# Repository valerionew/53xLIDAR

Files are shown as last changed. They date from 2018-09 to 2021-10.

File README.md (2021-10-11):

# 53xLIDAR

## Overview
Project for an opensource, all-in-one, solid state lidar.  
The lidar is made with 16 **VL53L1x** Time-of-flight IR ranging sensors.  

The sensors are operated by an **STM32F411RE** on two separate I2C buses, one for sensor 1-8, the other for 9-16. 
The XSHUTs are shared between two sensors on the two different I2C buses, while the sensors interrupts are separate for each sensor.   
For future use, there is an **LSM9DS1**, 9 DOF inertial sensor onboard.  

The lidar outputs the data via a virtual com port from the native Micro-USB, or via a 3.3V UART on a 4 pin JST-PH connector.  
Power (5V 100mA) is provided through the USB or via the 4 pin uart connector.

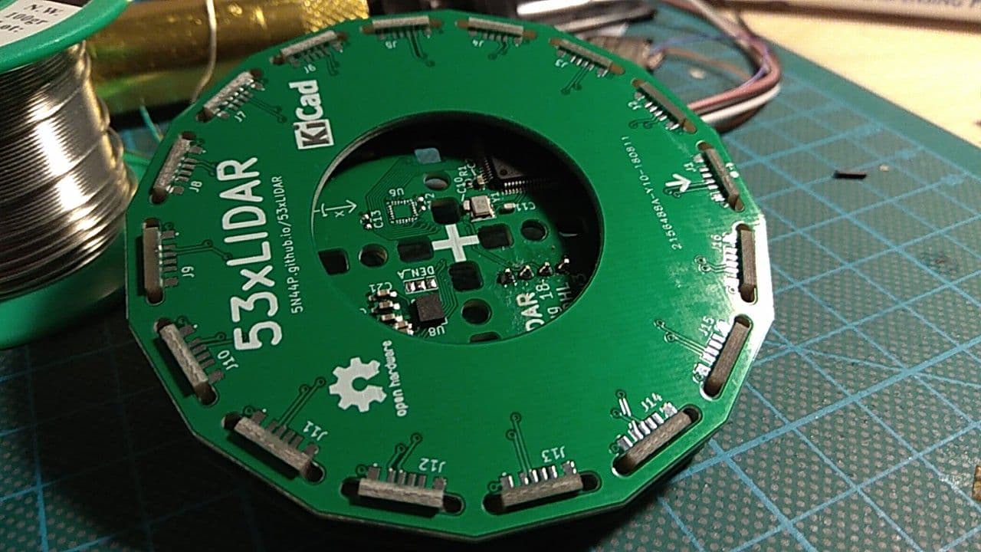
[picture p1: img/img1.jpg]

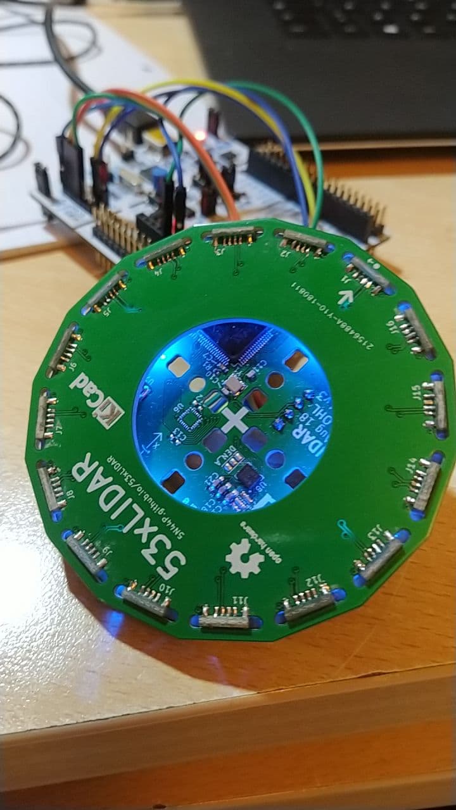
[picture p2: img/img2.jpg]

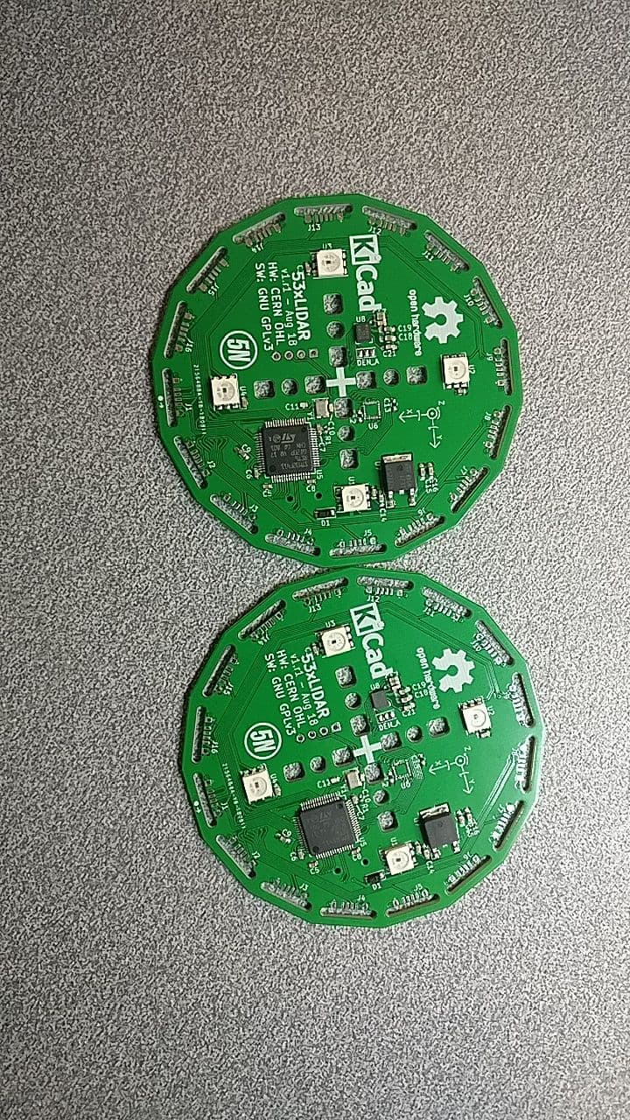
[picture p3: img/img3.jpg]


## Hardware
The hardware is designed in KiCAD and released under CERN OHL licence. 

It is formed by 16 sensor daughter boards, arranged in a 32 modules panel (only half panel is needed for one lidar, but for manufacturing reasons is made as a 32 modules panel); a bottom board containing all the electronics; a top board which brings the I2C line to the sensors and adds mechanical strenght and protection to the sensors.

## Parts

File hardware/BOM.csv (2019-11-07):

Id | Ref | Package | Quantity | Value
1 | C21 | C_0603_HandSoldering | 1 | 10n 16V
3 | J17 | USB_Mini-B_AdamTech_MUSB-B5-S-VT-TSMT-1_SMD_Vertical | 1 | USB_OTG
5 | U5 | LQFP-64_10x10mm_Pitch0.5mm | 1 | STM32F411RETx
7 | D1 | D_SOD-123 | 1 | USL1M
8 | J18 | JST_PH_B4B-PH-SM4-TB_04x2.00mm_Straight | 1 | UART_EXT
9 | J23 | JST_PH_B6B-PH-SM4-TB_06x2.00mm_Straight | 1 | SPI1_EXT
10 | U1;U2;U3;U4 | LED_WS2812-PLCC6 | 4 | WS2812S
11 | U7 | TO-252-2 | 1 | KF33_DPAK
13 | U6 | QFN-24_3x3mm_Pitch0.4mm | 1 | MPU-9250
14 | C10;C11 | C_0402 | 2 | 15p
15 | Y1 | Crystal_SMD_3225-4pin_3.2x2.5mm | 1 | 24MHz SR PASSIVES 3225-24M-SR
23 | R1 | R_0402 | 1 | 10k
24 | U8 | LGA-24L_3x3.5mm_Pitch0.43mm | 1 | LSM9DS1
25 | C9;C14;C15;C16;C18;C19;C2_MODULESx16 | C_0603_HandSoldering | 22 | 4.7u
26 | C1;C2;C3;C4;C5;C6;C7;C8;C12;C13;C17;C20;C22;C1_MODULESx16 | C_0603 | 29 | 100n
28 | R5_MODULESx16;R6_MODULESx16;R7_MODULESx16;R8_MODULESx16 | R_0603 | 64 | 10k
30 | U1_MODULES | ST_VL53L_HandSoldering | 16 | VL53L1X

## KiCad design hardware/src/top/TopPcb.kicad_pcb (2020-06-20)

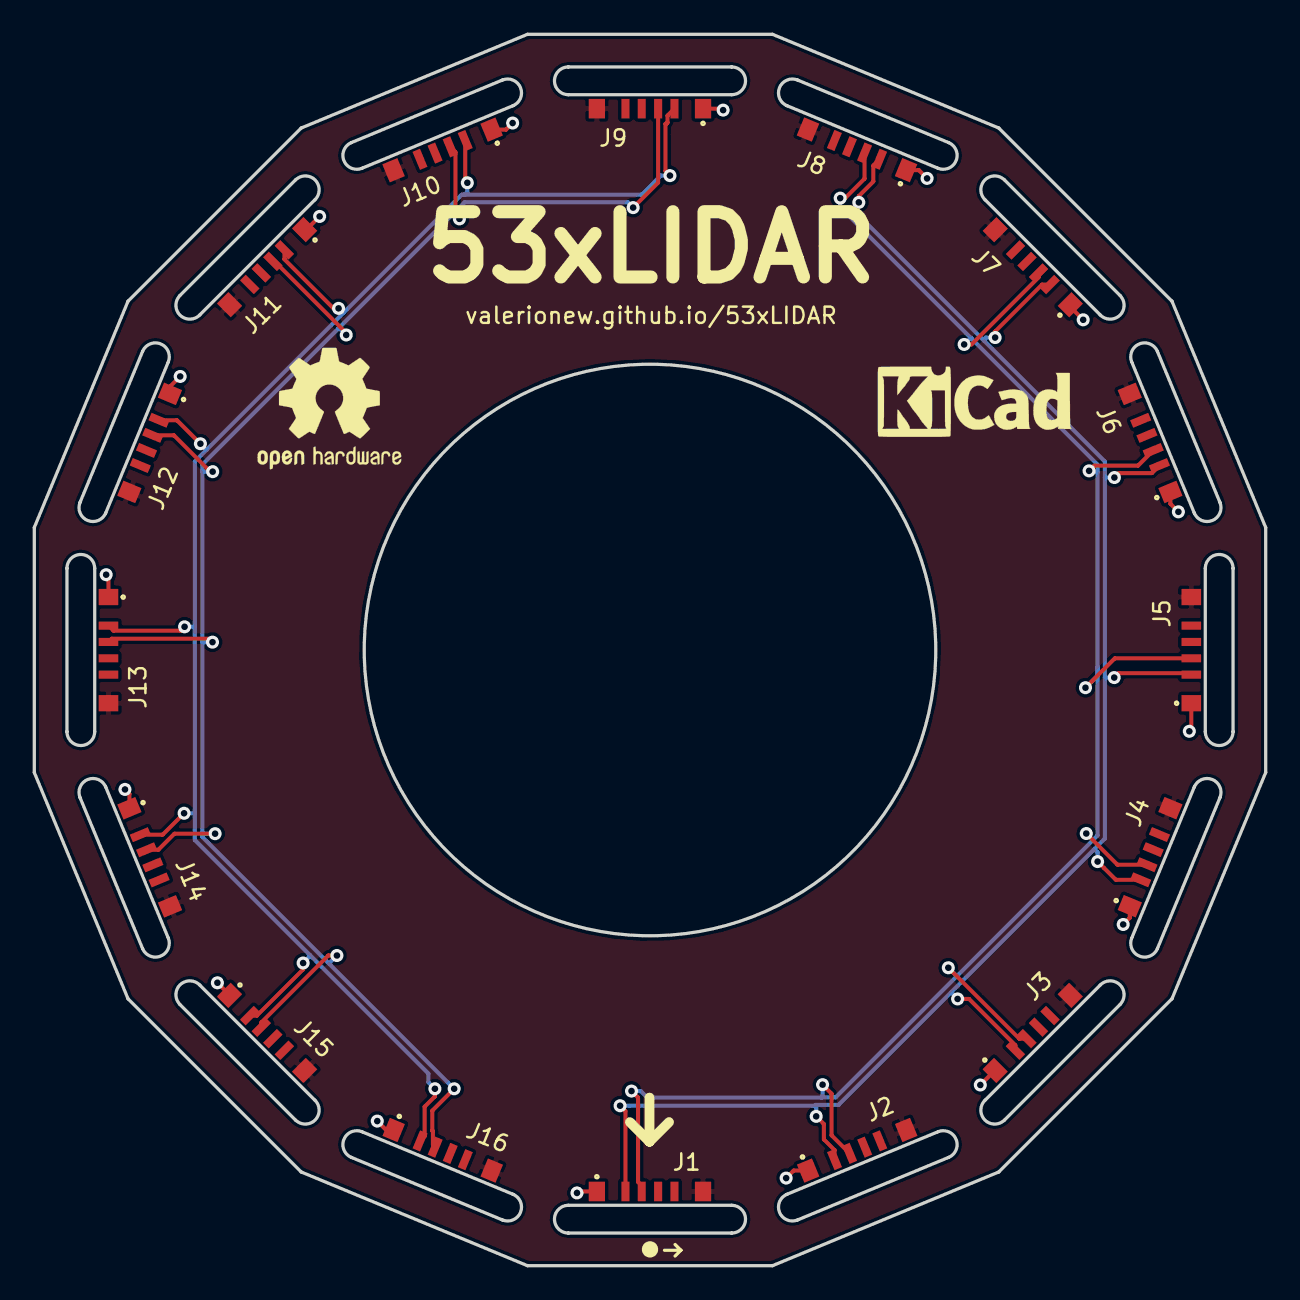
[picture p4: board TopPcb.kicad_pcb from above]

Board: 2 copper layers, 75.4 x 75.4 mm, 16 parts (0 on the bottom side), 6 nets.

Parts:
J1, J2, J3, J4, J5, J6, J7, J8, J9, J10, J11, J12, J13, J14, J15, J16: CONN_01X06; CONN

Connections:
+3V3: J1.1, J2.1, J3.1, J4.1, J5.1, J6.1, J7.1, J8.1, J9.1, J10.1, J11.1, J12.1, J13.1, J14.1, J15.1, J16.1
GND: J1.6, J2.6, J3.6, J4.6, J5.6, J6.6, J7.6, J8.6, J9.6, J10.6, J11.6, J12.6, J13.6, J14.6, J15.6, J16.6
SCL1: J1.3, J2.3, J3.3, J4.3, J5.3, J6.3, J7.3, J8.3
SCL2: J9.3, J10.3, J11.3, J12.3, J13.3, J14.3, J15.3, J16.3
SDA1: J1.2, J2.2, J3.2, J4.2, J5.2, J6.2, J7.2, J8.2
SDA2: J9.2, J10.2, J11.2, J12.2, J13.2, J14.2, J15.2, J16.2

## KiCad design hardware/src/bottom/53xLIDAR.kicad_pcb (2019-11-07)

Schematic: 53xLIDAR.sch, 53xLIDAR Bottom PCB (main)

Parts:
BOOT0_TP1: BOOT0; Measurement_Point_Round-SMD-Pad_Small
C1, C2, C3, C4, C5, C6, C7, C8, C12, C13, C17, C20, C22: 100n; C_0603
C9, C14, C15, C16, C18, C19: 4.7u; C_0603_HandSoldering
C10, C11: 15p; C_0402
C21: 10n 16V; C_0603_HandSoldering
D1: USL1M; D_SOD-123
J1, J2, J3, J4, J5, J6, J7, J8, J9, J10, J11, J12, J13, J14, J15, J16: CONN_01X06; CONN
J17: USB_OTG; miniusb_MUSB-B5-S-VT-TSMT-1
J18: UART_EXT; JST_PH_B4B-PH-SM4-TB_04x2.00mm_Straight
J19: I2C1_DEBUG; Pad_test_SMD_1x03_Pitch1.27mm
J20: I2C2_DEBUG; Pad_test_SMD_1x03_Pitch1.27mm
J21: UART_DEBUG; Pad_test_SMD_1x03_Pitch1.27mm
J22: SWD; Pin_Header_Straight_1x04_Pitch2.54mm
J23: SPI1_EXT; JST_PH_B6B-PH-SM4-TB_06x2.00mm_Straight
J25: GS3
R1: 10k; R_0402
U1, U2, U3, U4: WS2812S; LED_WS2812-PLCC6
U5: STM32F411RETx; LQFP-64_10x10mm_Pitch0.5mm
U6: MPU-9250; QFN-24_3x3mm_Pitch0.4mm
U7: KF33_DPAK; TO-252-2
U8: LSM9DS1; LGA-24L_3x3.5mm_Pitch0.43mm
Y1: 24MHz SR PASSIVES 3225-24M-SR; Crystal_SMD_3225-4pin_3.2x2.5mm

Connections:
+3V3: C5.1, C6.1, C7.1, C8.1, C12.2, C15.1, C16.1, C17.1, C18.1, C19.1, C20.2, J1.1, J2.1, J3.1, J4.1, J5.1, J6.1, J7.1, J8.1, J9.1, J10.1, J11.1, J12.1, J13.1, J14.1, J15.1, J16.1, J22.1, J23.1, J25.1, U5.13 (VREF+), U5.19 (VDD), U5.32 (VDD), U5.48 (VDD), U5.64 (VDD), U6.1, U6.8, U6.13, U7.3 (VO), U8.1, U8.3, U8.22, U8.23
EXT_CS: J23.5, U5.53 (PC12/I2S3_SD/SDIO_CK/SPI3_MOSI)
IMU_CS: U5.61 (I2C1_SCL/I2C3_SDA/I2S5_SD/SDIO_D4/SPI5_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), U6.22, U8.7
IMU_CS_MAG: U5.52 (PC11/ADC1_EXTI11/I2S3_ext_SD/SDIO_D3/SP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), U8.8
IMU_DRDY_MAG: U5.34 (I2S2_CK/I2S4_CK/SPI2_SCK/SPI4_SCK/TIM1_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), U8.9
IMU_INT: U5.54 (PD2/SDIO_CMD/TIM3_ETR), U6.12, U8.11
IMU_INT_MAG: U5.51 (PC10/I2S3_CK/SDIO_D2/SPI3_SCK), U8.10
INT1: J1.5, U5.24 (PC4/ADC1_IN14)
INT2: J2.5, U5.25 (PC5/ADC1_IN15)
INT3: J3.5, U5.26 (ADC1_IN8/I2S5_CK/SPI5_SCK/TIM1_CH2N/TIM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)
INT4: J4.5, U5.27 (ADC1_IN9/I2S5_WS/SPI5_NSS/TIM1_CH3N/TIM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)
INT5: J5.5, U5.28 (BOOT1/PB2)
INT6: J6.5, U5.35 (I2S2_ext_SD/SDIO_D6/SPI2_MISO/TIM1_CH2N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)
INT7: J7.5, U5.36 (ADC1_EXTI15/I2S2_SD/RTC_REFIN/SDIO_CK/S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)
INT8: J8.5, U5.37 (PC6/I2S2_MCK/SDIO_D6/TIM3_CH1/USART6_TX)
INT9: J9.5, U5.38 (PC7/I2S2_CK/I2S3_MCK/SDIO_D7/SPI2_SCK/T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)
INT10: J10.5, U5.39 (PC8/SDIO_D0/TIM3_CH3/USART6_CK)
INT11: J11.5, U5.4 (PC15/ADC1_EXTI15/RCC_OSC32_OUT)
INT12: J12.5, U5.2 (PC13/ANTI_TAMP/RTC_AF1)
INT13: J13.5, U5.3 (PC14/RCC_OSC32_IN)
INT14: J14.5, U5.62 (I2C1_SDA/I2C2_SDA/I2S2_WS/SDIO_D5/SPI2_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)
INT15: J15.5, U5.14 (ADC1_IN0/SYS_WKUP/TIM2_CH1/TIM2_ETR/TIM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)
INT16: J16.5, U5.15 (ADC1_IN1/I2S4_SD/SPI4_MOSI/TIM2_CH2/TIM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)
unnamed: BOOT0_TP1.1, R1.1, U5.60 (BOOT0)
unnamed: C9.2, U5.30 (VCAP1)
unnamed: C10.1, U5.5 (PH0/RCC_OSC_IN), Y1.3
unnamed: C11.1, U5.6 (PH1/RCC_OSC_OUT), Y1.1
unnamed: C13.2, U6.10
unnamed: C21.2, U8.21
unnamed: C22.1, U8.24
unnamed: D1.1, U1.3
unnamed: J25.2, U8.13
unnamed: U1.1, U2.2
unnamed: U2.1, U3.2
unnamed: U3.1, U4.2
SCL1: J1.3, J2.3, J3.3, J4.3, J5.3, J6.3, J7.3, J8.3, J19.1, U5.58 (I2C1_SCL/TIM4_CH1/USART1_TX/PB6)
SCL2: J9.3, J10.3, J11.3, J12.3, J13.3, J14.3, J15.3, J16.3, J20.1, U5.29 (I2C2_SCL/I2S2_CK/I2S3_MCK/SDIO_D7/SPI2_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)
SCL_IMU: J23.4, U5.33 (I2C2_SMBA/I2S2_WS/I2S3_CK/I2S4_WS/SPI2_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), U5.41 (I2C3_SCL/RCC_MCO_1/SDIO_D1/TIM1_CH1/USA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), U6.23, U8.2
SDA1: J1.2, J2.2, J3.2, J4.2, J5.2, J6.2, J7.2, J8.2, J19.2, U5.59 (I2C1_SDA/SDIO_D0/TIM4_CH2/USART1_RX/PB7)
SDA2: J9.2, J10.2, J11.2, J12.2, J13.2, J14.2, J15.2, J16.2, J20.2, U5.55 (I2C2_SDA/I2S1_CK/I2S3_CK/SPI1_SCK/SPI3_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)
SDA_IMU: J23.2, U5.40 (PC9/I2C3_SDA/I2S_CKIN/RCC_MCO_2/SDIO_D1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), U5.57 (I2C1_SMBA/I2S1_SD/I2S3_SD/SDIO_D3/SPI1_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), U6.24, U8.4
SPI1_MISO: J23.3, U5.56 (I2C3_SDA/I2S3_ext_SD/SDIO_D0/SPI1_MISO/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), U6.9, U8.5, U8.6
SWCLK_PROGRAMMING: J22.3, U5.49 (SYS_JTCK-SWCLK/PA14)
SWDIO_PROGRAMMING: J22.2, U5.46 (SYS_JTMS-SWDIO/PA13)
USART_DEBUG_RX: J21.1, U5.17 (ADC1_IN3/I2S2_MCK/TIM2_CH4/TIM5_CH4/TIM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)
USART_DEBUG_TX: J21.2, U5.16 (ADC1_IN2/I2S_CKIN/TIM2_CH3/TIM5_CH3/TIM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)
USART_EXT_RX: J18.2, U5.43 (I2S5_SD/SPI5_MOSI/TIM1_CH3/USART1_RX/US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)
USART_EXT_TX: J18.1, U5.42 (I2C3_SMBA/SDIO_D2/TIM1_CH2/USART1_TX/US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)
USB_D+: J17.3, U5.45 (SPI5_MISO/TIM1_ETR/USART1_RTS/USART6_RX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)
USB_D-: J17.2, U5.44 (ADC1_EXTI11/SPI4_MISO/TIM1_CH4/USART1_C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)
USB_VBUS: C1.1, C2.1, C3.1, C4.1, C14.1, D1.2, J17.1, J18.3, U1.5, U2.3, U2.5, U3.3, U3.5, U4.3, U4.5, U7.1 (VI)
WS2812S_DATA: U1.2, U5.50 (ADC1_EXTI15/I2S1_WS/I2S3_WS/SPI1_NSS/SP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)
XSHUT1: J8.4, J9.4, U5.8 (PC0/ADC1_IN10)
XSHUT2: J7.4, J10.4, U5.9 (PC1/ADC1_IN11)
XSHUT3: J6.4, J11.4, U5.10 (PC2/ADC1_IN12/I2S2_ext_SD/SPI2_MISO)
XSHUT4: J5.4, J12.4, U5.11 (PC3/ADC1_IN13/I2S2_SD/SPI2_MOSI)
XSHUT5: J4.4, J13.4, U5.20 (ADC1_IN4/I2S1_WS/I2S3_WS/SPI1_NSS/SPI3_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)
XSHUT6: J3.4, J14.4, U5.21 (ADC1_IN5/I2S1_CK/SPI1_SCK/TIM2_CH1/TIM2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)
XSHUT7: J2.4, J15.4, U5.22 (ADC1_IN6/I2S2_MCK/SDIO_CMD/SPI1_MISO/TI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)
XSHUT8: J1.4, J16.4, U5.23 (ADC1_IN7/I2S1_SD/SPI1_MOSI/TIM1_CH1N/TI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)

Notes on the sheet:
SET THE UNUSED ONE TO HIGH IMPEDANCE

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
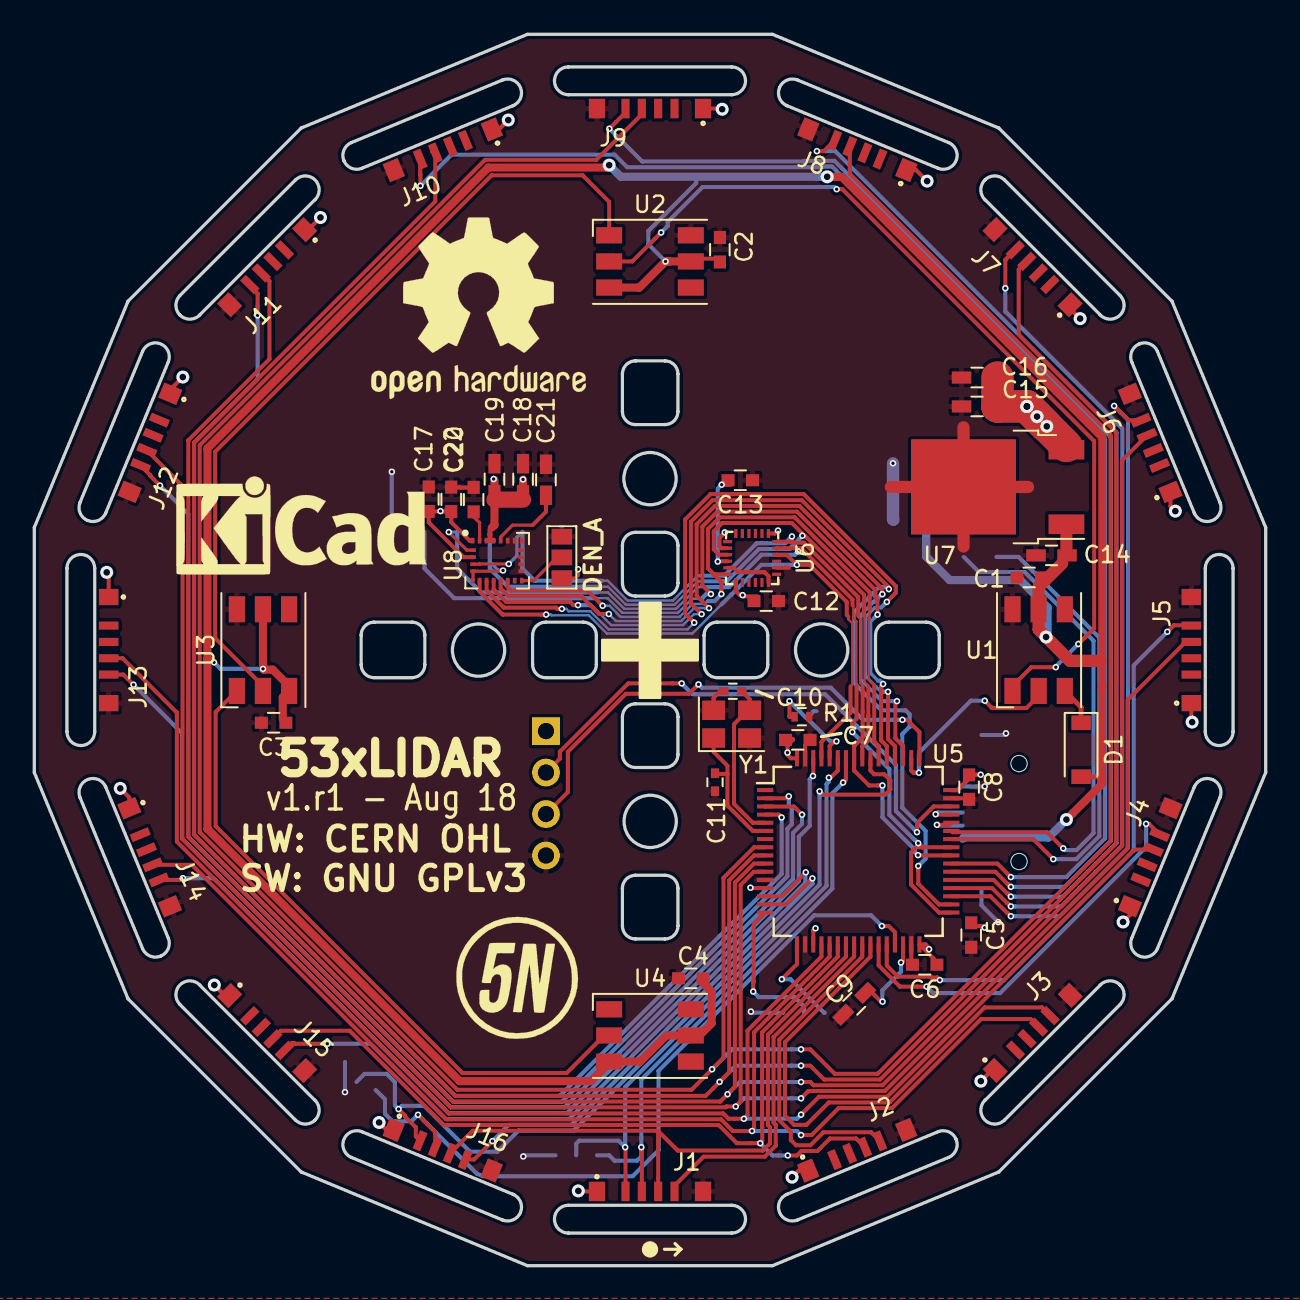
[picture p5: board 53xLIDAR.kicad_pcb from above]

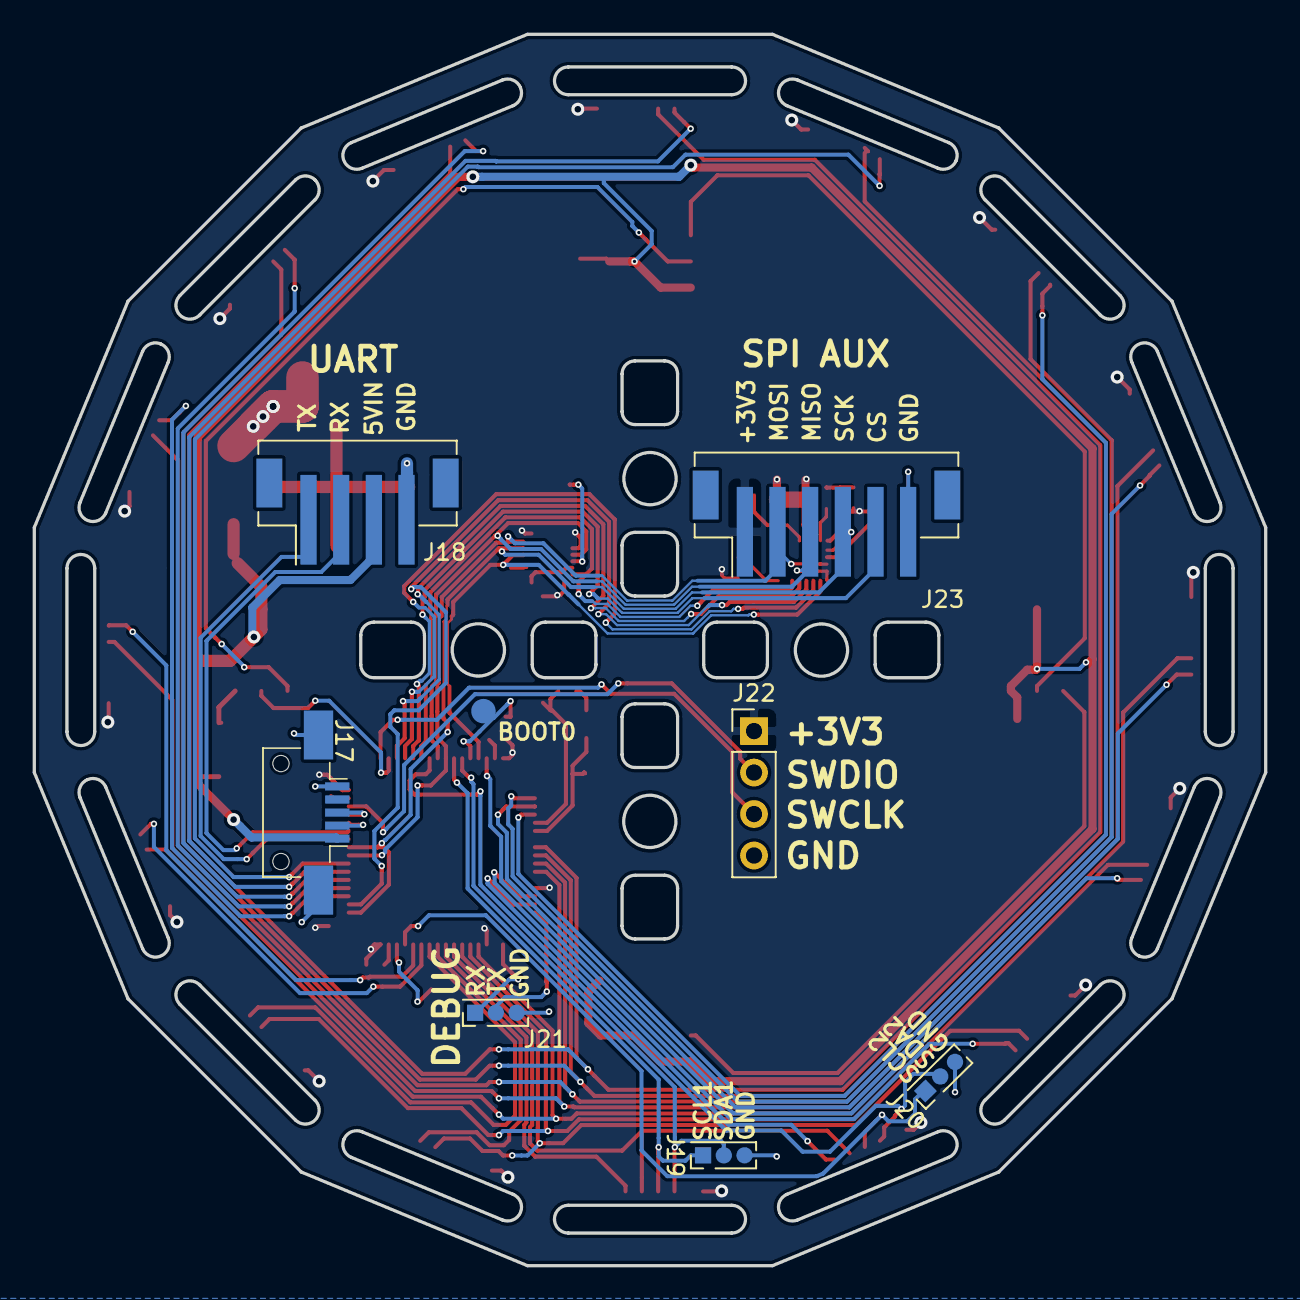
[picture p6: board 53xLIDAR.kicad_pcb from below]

Board: 2 copper layers, 75.4 x 75.4 mm, 58 parts (8 on the bottom side), 61 nets.

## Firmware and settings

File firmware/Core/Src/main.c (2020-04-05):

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

/* Includes ------------------------------------------------------------------*/
#include "main.h"
#include "usb_device.h"

/* USER CODE BEGIN Includes */
#include "VL53L1X_api.h"

#include "WS2812.h"
/* USER CODE END Includes */

I2C_HandleTypeDef hi2c1;
I2C_HandleTypeDef hi2c2;
I2C_HandleTypeDef hi2c3;

SPI_HandleTypeDef hspi3;

UART_HandleTypeDef huart1;
UART_HandleTypeDef huart2;

void SystemClock_Config(void);
static void MX_GPIO_Init(void);
static void MX_I2C1_Init(void);
static void MX_I2C2_Init(void);
static void MX_I2C3_Init(void);
static void MX_SPI3_Init(void);
static void MX_USART1_UART_Init(void);
static void MX_USART2_UART_Init(void);
/* USER CODE BEGIN 0 */
struct Gpio {
	GPIO_TypeDef * const port;
	const uint16_t mask;
};

struct Gpio leds = { GPIOA, GPIO_PIN_15 };

struct Gpio xshut[] = { { GPIOC, GPIO_PIN_0 }, { GPIOC, GPIO_PIN_1 }, { GPIOC,
GPIO_PIN_2 }, { GPIOC, GPIO_PIN_3 }, { GPIOA, GPIO_PIN_4 }, { GPIOA,
GPIO_PIN_5 }, { GPIOA, GPIO_PIN_6 }, { GPIOA, GPIO_PIN_7 }, };
/*
 uint8_t interruptLidar[] = {
 PC4, PC5, PB0, PB1, PB2, PB14, PB15, PC6, PC7, PC8, PC15, PC13, PC14, PB9, PA0, PA1
 };
 */

struct {
	uint16_t dev;
	uint8_t valid;
} sensors[16];

int enableSensor(int i) {

	uint16_t dev = 0x29 << 1;
	if (i >= 8) {
		dev |= 0x100; //if 9th bit is 0 it will use I2C1,if 1 will use i2c2
	}
	
	VL53L1X_Error err;
	uint8_t is_booted = 0;
	do{
		err = VL53L1X_BootState(dev, &is_booted);
		HAL_Delay(2);
	}while(!is_booted && err == VL53L1_ERROR_NONE);
	
	if (err != VL53L1_ERROR_NONE) {
		uint8_t msg[] = "VL53L1X_BootState failed    \n";
		uint8_t len = sizeof(msg) - 1;
		msg[len - 1 - 1] = i + '0';
		msg[len - 3 - 1] = err + '0';
		HAL_UART_Transmit(&huart1, msg, len, 0xFFFF);
		return 1;
	} else {
		uint8_t msg[] = "VL53L1X_BootState OK  \n";
		uint8_t len = sizeof(msg) - 1;
		msg[len - 1 - 1] = i + '0';
		HAL_UART_Transmit(&huart1, msg, len, 0xFFFF);
	}
	
	/* Sensor Initialization */
	err = VL53L1X_SensorInit(dev);
	if (err != VL53L1_ERROR_NONE) {
		uint8_t msg[] = "VL53L1X_SensorInit failed    \n";
		uint8_t len = sizeof(msg) - 1;
		msg[len - 1 - 1] = i + '0';
		msg[len - 3 - 1] = err + '0';
		HAL_UART_Transmit(&huart1, msg, len, 0xFFFF);
		return 3;
	} else {
		uint8_t msg[] = "VL53L1X_SensorInit OK  \n";
		uint8_t len = sizeof(msg) - 1;
		msg[len - 1 - 1] = i + '0';
		HAL_UART_Transmit(&huart1, msg, len, 0xFFFF);
	}
	
	/* Modify the default configuration */
	err = VL53L1X_SetI2CAddress(dev, (0x29 + i + 1) << 1);
	dev = (0x29 + i + 1) << 1;
	if (i >= 8) {
		dev |= 0x100; //if 9th bit is 0 it will use I2C1,if 1 will use i2c2
	}
	if (err != VL53L1_ERROR_NONE) {
		uint8_t msg[] = "VL53L1X_SetI2CAddress failed    \n";
		uint8_t len = sizeof(msg) - 1;
		msg[len - 1 - 1] = i + '0';
		msg[len - 3 - 1] = err + '0';
		HAL_UART_Transmit(&huart1, msg, len, 0xFFFF);
		return 2;
	} else {
		uint8_t msg[] = "VL53L1X_SetI2CAddress OK  \n";
		uint8_t len = sizeof(msg) - 1;
		msg[len - 1 - 1] = i + '0';
		HAL_UART_Transmit(&huart1, msg, len, 0xFFFF);
	}
	
	err = VL53L1X_SetDistanceMode(dev, 2); // 2 = VL53L1X_DISTANCEMODE_LONG
	if (err != VL53L1_ERROR_NONE) {
		uint8_t msg[] = "VL53L1X_SetDistanceMode failed    \n";
		uint8_t len = sizeof(msg) - 1;
		msg[len - 1 - 1] = i + '0';
		msg[len - 3 - 1] = err + '0';
		HAL_UART_Transmit(&huart1, msg, len, 0xFFFF);
		return 5;
	} else {
		uint8_t msg[] = "VL53L1X_SetDistanceMode OK  \n";
		uint8_t len = sizeof(msg) - 1;
		msg[len - 1 - 1] = i + '0';
		HAL_UART_Transmit(&huart1, msg, len, 0xFFFF);
	}

	err = VL53L1X_SetTimingBudgetInMs(dev, 20);
	if (err != VL53L1_ERROR_NONE) {
		uint8_t msg[] =
				"VL53L1X_SetTimingBudgetInMs failed    \n";
		uint8_t len = sizeof(msg) - 1;
		msg[len - 1 - 1] = i + '0';
		msg[len - 3 - 1] = err + '0';
		HAL_UART_Transmit(&huart1, msg, len, 0xFFFF);
		return 6;
	} else {
		uint8_t msg[] = "VL53L1X_SetTimingBudgetInMs OK  \n";
		uint8_t len = sizeof(msg) - 1;
		msg[len - 1 - 1] = i + '0';
		HAL_UART_Transmit(&huart1, msg, len, 0xFFFF);
	}

	err = VL53L1X_SetInterMeasurementInMs(dev, 25);
	if (err != VL53L1_ERROR_NONE) {
		uint8_t msg[] =
				"VL53L1X_SetInterMeasurementInMs failed    \n";
		uint8_t len = sizeof(msg) - 1;
		msg[len - 1 - 1] = i + '0';
		msg[len - 3 - 1] = err + '0';
		HAL_UART_Transmit(&huart1, msg, len, 0xFFFF);
		return 7;
	} else {
		uint8_t msg[] = "VL53L1X_SetInterMeasurementInMs OK  \n";
		uint8_t len = sizeof(msg) - 1;
		msg[len - 1 - 1] = i + '0';
		HAL_UART_Transmit(&huart1, msg, len, 0xFFFF);
	}

	err = VL53L1X_StartRanging(dev);
	if (err != VL53L1_ERROR_NONE) {
		uint8_t msg[] = "VL53L1X_StartRanging failed    \n";
		uint8_t len = sizeof(msg) - 1;
		msg[len - 1 - 1] = i + '0';
		msg[len - 3 - 1] = err + '0';
		HAL_UART_Transmit(&huart1, msg, len, 0xFFFF);
		return 8;
	} else {
		uint8_t msg[] = "VL53L1X_StartRanging OK  \n";
		uint8_t len = sizeof(msg) - 1;
		msg[len - 1 - 1] = i + '0';
		HAL_UART_Transmit(&huart1, msg, len, 0xFFFF);
	}
	
	sensors[i].dev = dev;
	sensors[i].valid = 1;
	
	return 0;
}

void scan(I2C_HandleTypeDef *hi2c) {
	for (int i = 1; i < 128; i++) {
		/*
		 * the HAL wants a left aligned i2c address
		 * &hi2c1 is the handle
		 * (uint16_t)(i<<1) is the i2c address left aligned
		 * retries 2
		 * timeout 2
		 */
		HAL_StatusTypeDef result = HAL_I2C_IsDeviceReady(hi2c, (i << 1), 2, 2);
		if (result != HAL_OK) // HAL_ERROR or HAL_BUSY or HAL_TIMEOUT
				{
			HAL_UART_Transmit(&huart1, (uint8_t*)".", 1, 0xFFFF);
		}
		if (result == HAL_OK) {
			char buff[80];
			sprintf(buff, "0x%X\n", i << 1);
			HAL_UART_Transmit(&huart1, (uint8_t*)buff, strlen(buff), 0xFFFF);
		}
	}
	char buff[] = "\nSCAN FINISH\n";
	HAL_UART_Transmit(&huart1, (uint8_t*)buff, strlen(buff), 0xFFFF);
}

uint32_t ledColor[4];

void updateLed() {
	static int lastGreen = 0;
	static uint8_t first = 1;
	static uint32_t last = 0;
	if (!first) {
		// set back previus led
		if (lastGreen == 0) {
			ledColor[3] = last;
		} else {
			ledColor[lastGreen - 1] = last;
		}
	} else {
		first = 0;
	}
	//set current to blue and increment
	last = ledColor[lastGreen];
	ledColor[lastGreen] = 0x00FF00; //blue
	lastGreen++;

	//avoid overflow
	if (lastGreen >= 4) {
		lastGreen = 0;
	}

	sendColors(ledColor, 4);
}

/* USER CODE END 0 */

/**
  * @brief  The application entry point.
  * @retval int
  */
int main(void)
{
  /* MCU Configuration--------------------------------------------------------*/

  /* Reset of all peripherals, Initializes the Flash interface and the Systick. */
  HAL_Init();

  /* Configure the system clock */
  SystemClock_Config();

  /* Initialize all configured peripherals */
  MX_GPIO_Init();
  MX_I2C1_Init();
  MX_I2C2_Init();
  MX_I2C3_Init();
  MX_SPI3_Init();
  MX_USART1_UART_Init();
  MX_USART2_UART_Init();
  MX_USB_DEVICE_Init();
  /* USER CODE BEGIN 2 */
	// be sure to put all xshut to low
	HAL_GPIO_WritePin(GPIOC, GPIO_PIN_0 | GPIO_PIN_1 | GPIO_PIN_2 | GPIO_PIN_3,
			GPIO_PIN_RESET);
	HAL_GPIO_WritePin(GPIOA, GPIO_PIN_4 | GPIO_PIN_5 | GPIO_PIN_6 | GPIO_PIN_7,
			GPIO_PIN_RESET);

	for (int i = 0; i < 4; i++) {
		ledColor[i] = 0x0000FF; //set to blue
	}
	sendColors(ledColor, 4);

	HAL_Delay(1000);

	for (int i = 0; i < 8; i++) {
		HAL_GPIO_WritePin(xshut[i].port, xshut[i].mask, GPIO_PIN_SET);
		HAL_Delay(10);
		int error = 0;
		error += enableSensor(i); //i2c1
		error += enableSensor(i + 8); //i2c2

		if (error) {
			//HAL_GPIO_WritePin(xshut[i].port, xshut[i].mask, GPIO_PIN_RESET);
			ledColor[i / 2] = 0xFF0000; //set to red
			sendColors(ledColor, 4);
		} else {
			if (ledColor[i / 2] != 0xFF0000) {
				ledColor[i / 2] = 0; //turn off led
				sendColors(ledColor, 4);
			}
		}
	}
	scan(&hi2c1);
	scan(&hi2c2);

	int fps = 0;
	uint8_t buff[80];

	uint8_t msg[5]; // ~, 3 byte payload, checksum
	uint32_t start = HAL_GetTick();
	while (1) {
	
		for (int i = 0; i < 16; i++) {
		
			if (sensors[i].valid) {
				uint8_t ready = 0;
				VL53L1X_ERROR err = VL53L1X_CheckForDataReady(sensors[i].dev, &ready);
				
				if (!err && ready) {
					uint8_t range_status;
					err = VL53L1X_GetRangeStatus(sensors[i].dev, &range_status);
					if (err) {
						sprintf((char*) buff, "VL53L1X_GetRangeStatus error %d on sensor %d\n", err, i);
						HAL_UART_Transmit(&huart1, buff, strlen((char*) buff), 0xFFFF);
						continue;
					}
					
					uint16_t distance_mm;
					err = VL53L1X_GetDistance(sensors[i].dev, &distance_mm);
					if (err) {
						sprintf((char*) buff, "VL53L1X_GetDistance error %d on sensor %d\n", err, i);
						HAL_UART_Transmit(&huart1, buff, strlen((char*) buff), 0xFFFF);
						continue;
					}
					
					err = VL53L1X_ClearInterrupt(sensors[i].dev);
					if (err) {
						sprintf((char*) buff, "VL53L1X_ClearInterrupt error %d on sensor %d\n", err, i);
						HAL_UART_Transmit(&huart1, buff, strlen((char*) buff), 0xFFFF);
						continue;
					}

					msg[0] = '~';
					msg[1] = i;
					msg[2] = distance_mm;
					msg[3] = distance_mm >> 8;
					msg[4] = msg[0] + msg[1] + msg[2] + msg[3];

					sprintf((char*) buff, "%x\t%d\n", i, distance_mm);
					HAL_UART_Transmit(&huart1, buff, strlen((char*) buff), 0xFFFF);

					fps++;
				} else if (err) {
					sprintf((char*) buff, "VL53L1X_CheckForDataReady error %d on sensor %d\n", err, i);
					HAL_UART_Transmit(&huart1, buff, strlen((char*) buff), 0xFFFF);
					/*
					 maxErr--;
					 if (!maxErr){
					 sprintf((char*) buff, "reset\n");
					 HAL_UART_Transmit(&huart1, buff, strlen((char*) buff), 0xFFFF);
					 scan(&hi2c1);
					 MX_I2C1_Init();
					 scan(&hi2c1);
					 }
					 */
				} else {
					//sprintf((char*) buff, "not ready\n");0
					//HAL_UART_Transmit(&huart1, buff, strlen((char*) buff), 0xFFFF);
				}
			}
		}

		static uint32_t startLedSpin = 0;
		if (HAL_GetTick() - startLedSpin >= 100) {
			startLedSpin = HAL_GetTick();
			updateLed();
		}

		if (HAL_GetTick() - start >= 1000) {
			start = HAL_GetTick();
			sprintf((char*) buff, "FPS: %d\n", fps);
			HAL_UART_Transmit(&huart1, buff, strlen((char*) buff), 0xFFFF);
			fps = 0;
		}

	}
  /* USER CODE END 2 */

  /* Infinite loop */
  /* USER CODE BEGIN WHILE */
  while (1)
  {
    /* USER CODE END WHILE */

    /* USER CODE BEGIN 3 */
  }
  /* USER CODE END 3 */
}

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


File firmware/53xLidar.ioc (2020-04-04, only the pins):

Mcu.UserName=STM32F411RETx
PA0-WKUP.Signal=GPIO_Input
PA1.Signal=GPIO_Input
PA10.Signal=USART1_RX
PA11.Signal=USB_OTG_FS_DM
PA12.Signal=USB_OTG_FS_DP
PA13.Signal=SYS_JTMS-SWDIO
PA14.Signal=SYS_JTCK-SWCLK
PA15.Signal=GPIO_Output
PA2.Signal=USART2_TX
PA3.Signal=USART2_RX
PA4.Signal=GPIO_Output
PA5.Signal=GPIO_Output
PA6.Signal=GPIO_Output
PA7.Signal=GPIO_Output
PA8.Signal=I2C3_SCL
PA9.Signal=USART1_TX
PB0.Signal=GPIO_Input
PB1.Signal=GPIO_Input
PB10.Signal=I2C2_SCL
PB12.Signal=SPI3_SCK
PB14.Signal=GPIO_Input
PB15.Signal=GPIO_Input
PB2.Signal=GPIO_Input
PB3.Signal=I2C2_SDA
PB4.Signal=SPI3_MISO
PB5.Signal=SPI3_MOSI
PB6.Signal=I2C1_SCL
PB7.Signal=I2C1_SDA
PB8.Signal=GPIO_Output
PB9.Signal=GPIO_Input
PC0.Signal=GPIO_Output
PC1.Signal=GPIO_Output
PC12.Signal=GPIO_Output
PC13-ANTI_TAMP.Signal=GPIO_Input
PC14-OSC32_IN.Signal=GPIO_Input
PC15-OSC32_OUT.Signal=GPIO_Input
PC2.Signal=GPIO_Output
PC3.Signal=GPIO_Output
PC4.Signal=GPIO_Input
PC5.Signal=GPIO_Input
PC6.Signal=GPIO_Input
PC7.Signal=GPIO_Input
PC8.Signal=GPIO_Input
PC9.Signal=I2C3_SDA
PD2.Signal=GPIO_Input

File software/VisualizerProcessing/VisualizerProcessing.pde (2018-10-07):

import processing.serial.*;

int bgcolor = 0xff;     // Background color
int fgcolor = 0;  // Fill color
Serial myPort;       // The serial port

float points[] = new float[16];
int pointsColor[] = new color[16];

class Point2D {
  float x, y;
  Point2D( float x, float y ) {
    this.x = x;
    this.y = y;
  }
}

class Point2DColored extends Point2D {
  int r;
  int g;
  int b;
  Point2DColored(float x, float y, int r, int g, int b) {
    super(x, y);
    this.r = r;
    this.g = g;
    this.b = b;
  }
}


void setup() {
  //fullScreen(P2D);

  size(1000, 1000);  // Stage size

  frameRate(30);

  surface.setResizable(true);
  noStroke();      // No border on the next thing drawn

  // Print a list of the serial ports, for debugging purposes:
  printArray(Serial.list());

  //String portName = Serial.list()[0];
  String portName = "/dev/ttyUSB0";
  myPort = new Serial(this, portName, 115200);

  //                       thread("loop");
}

void loop() {
  String[] lines = loadStrings("logTest.txt");
  for (int i = 200; i < lines.length; i++) {
    for (char c : lines[i].toCharArray()) {
      analize((byte)c);
    }
    analize((byte)'\n');
    delay(20);
  }
  exit();
}

void draw() {
  background(bgcolor);
  fill(fgcolor);
  println("draw");

  // Set the starting position of the point
  int xpos = width/2;
  int ypos = height/2;
 

  int xOffset = 0, yOffset = 0;
  if (width < height) {
    xpos = width/2;
    ypos = width/2;
    yOffset = (height - width)/2;
  } else {
    xpos = height/2;
    ypos = height/2;
    xOffset = (width - height)/2;
  }

  float divider = 0.1;
  
  
  textSize(32);
  fill(255, 0, 0);
  text("1 circle = 1 meter", 80, ypos);
  fill(0, 0, 0);
  text("1 circle = 0.1 meter", 80, ypos - 32);

  /* DRAW ONE CICLE EVERY METER */
  noFill();
  stroke(0, 0, 0);
  for (int i=0; i < 10; i++) {
    float distance = sqrt(100*i) / divider;
    ellipse(xpos+xOffset, ypos+yOffset, distance*2, distance*2);
  }
  
  for (int i=0; i <= 3; i++) {
    float distance = sqrt(1000*i) / divider;
    stroke(255, 0, 0);
    ellipse(xpos+xOffset, ypos+yOffset, distance*2, distance*2);
  }

  /* Draw the lines*/
  stroke(220, 220, 220);
  float angleLines = 0;
  for (int i=0; i < points.length; i++) {
    float x = xpos*cos(-radians(angleLines)) + xpos + xOffset;
    float y = ypos*sin(-radians(angleLines)) + ypos + yOffset;
    float x1 = -xpos*cos(-radians(angleLines)) + xpos + xOffset;
    float y1 = -ypos*sin(-radians(angleLines)) + ypos + yOffset;
    line(x1, y1, x, y);
    if (i == 0)
      x -= 20;
    if (i == 4)
      y += 30;
      
    text((i + 1)+"", x, y);
    angleLines += (360.0/points.length);
  }

  // Draw the points
  for (int i=0; i < points.length; i++) {
    float distance;
    if ( Float.isNaN(points[i]) || pointsColor[i] == 0 ) {
      distance = Math.max(xpos, ypos)*2;
      distance=0;
      stroke(213, 166, 166);
      fill(213, 166, 166);
    } else {
      distance = sqrt(points[i]) / divider;//sqrt(points[i]);
      //distance = sqrt(points[i] / divider * xpos);
      println("distance: "+distance);
      stroke(0, 0, 128);
      pointsColor[i] -= 20;
      fill(0, 0, 255, pointsColor[i]);
      
    }
    float angle = (float)(360.0 / points.length) * i;
    float fill = (float)(360.0 / points.length)/2;

    arc(xpos+xOffset, ypos+yOffset, distance*2, distance*2, radians(-angle-fill), radians(-angle+fill));
    float x = distance * cos( -radians(angle) );
    float y = distance * sin( -radians(angle) );
    /*
    stroke(0, 128, 0);
    fill(0, 255, 0);
    ellipse(x+xpos+xOffset, y+ypos+yOffset, Math.max(points[i] / divider * 10, 4), Math.max(points[i] / divider * 10, 4));
    */
    //ellipse(x+xpos+xOffset, y+ypos+yOffset, 4,4);
  }
}

void serialEvent(Serial myPort) {
  try {
    int inByte = myPort.read();
    if (inByte == -1) {
      return;
    }
    analize((byte)inByte);
  }
  catch(Exception e) {
    e.printStackTrace();
  }
}

float valuesSum[] = new float[16];
int valuesNum[] = new int[16];

boolean valid = false;
int total = 0;
char message[] = new char[100];
void analize(byte inByte) {
  // read a byte from the serial port:

  if ('\n' == inByte) {

    if (!valid) {
      println("valid!");
      valid = true;
      total = 0;
      return;
    }
    if (total < 4) {
      println("invalid len! "+total);
      total = 0;
      return;
    }
    if (message[1] != '\t' || message[2] == '-') {
      println("invalid - "+message[1]+" - " +message[2] + new String(message));
      total = 0;
      return;
    }

    int sensor;
    if (message[0] >= 'a') {
      sensor = message[0] - 'a' + 10;
    } else {
      sensor = message[0] - '0';
    }

    int val = 0;
    for (int i = 2; i < total; i++) {
      val *= 10;
      val += message[i] - '0';
    }
    println("value "+sensor+" "+val);
    
    
    valuesSum[sensor] += val;
    valuesNum[sensor]++;
    
    points[sensor] = valuesSum[sensor] / valuesNum[sensor];
    pointsColor[sensor] = 255;
    
    if (valuesNum[sensor] > 2){
      valuesSum[sensor] -= points[sensor];
      valuesNum[sensor]--;
    }
    
    total = 0;
    return;
  }

  if (!valid)
    return;

  message[total] = (char)inByte;
  total += 1;
  if (total >= message.length) {
    println("invalid too long " + new String(message));
    total = 0;
    valid = false;
  }
}

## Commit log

2018-08-06 cubeMX raw project, exported as SW4STM32, initial stm32duino variant creation. come bug in board.txt, it does not find the conf file...
2018-08-07 fixed stencil for CONN footprints
    [53xLIDAR.kicad_pcb, TopPcb.kicad_pcb]
2018-08-07 fixed manufactury requirements
    [TopPcb.kicad_pcb, module.kicad_pcb]
2018-08-10 added LSM9DS1, revision 1
    [53xLIDAR.kicad_pcb, 53xLIDAR.sch]
2018-08-10 Revision 1
    [53xLIDAR.kicad_pcb, 53xLIDAR.sch]
2018-08-10 Bom optimization
    [53xLIDAR.kicad_pcb, 53xLIDAR.sch]
2018-08-10 New gerbers
2018-08-11 Fixed bugs introduced in rev1
    [53xLIDAR.kicad_pcb]
2018-08-11 Removed IMU axes on silkscreen as they are no longer consistent with the two IMUs
    [53xLIDAR.kicad_pcb]
2018-08-14 Added BOM
    [BOM.csv]
2018-09-30 added ws2812 support, and different other modification to try make this sensors stable
2020-04-04 Moved to the new STM32CubeIDE environment, new VL53L1 APIs not working yet
    [53xLidar.ioc, WS2812.c, main.c]
2020-04-05 updated platform to work with stm32f4
2020-04-05 fixed compilation error, maybe
    [vl53l1_platform.c]
2020-04-05 fixed for real, now it compiles
    [main.c, vl53l1_platform.c]

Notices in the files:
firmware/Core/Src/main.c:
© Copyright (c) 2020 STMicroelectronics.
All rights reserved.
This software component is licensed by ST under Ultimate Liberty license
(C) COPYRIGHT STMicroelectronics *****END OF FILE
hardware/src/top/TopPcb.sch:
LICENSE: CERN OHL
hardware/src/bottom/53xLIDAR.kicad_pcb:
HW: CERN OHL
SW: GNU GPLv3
